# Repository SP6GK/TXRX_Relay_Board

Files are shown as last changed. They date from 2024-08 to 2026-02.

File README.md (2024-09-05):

# TXRX_Relay_Board
A PCB for switching the signal path between RX and TX in a high-power HF amplifier, such as the Forte 600. It includes RX/TX relays, an input SWR bridge, and analog input over power protection.

For the theory of operation and functionality, please refer to section 2.2.1 of the Forte 600 documentation [link](https://github.com/SP6GK/Forte-600-HF-RF-Amplifier/blob/main/Optimization_HF_amplifier_TLT_Forte600Documentation.pdf).

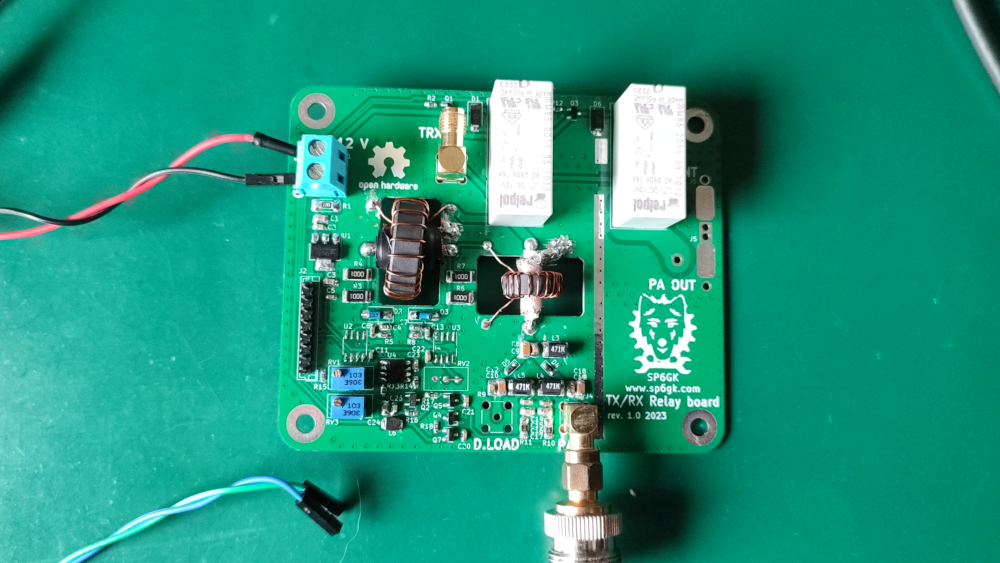
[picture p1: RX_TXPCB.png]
PCB Image


## Change log:
### 05.09.2024 - rev 1.2:
- Removed unconnected tracks and fixed some footprint libraries, as well as the relative path to the custom schematic template (thanks to vk4kyt for pointing this out).
- Changed NPN and PNP transistors to more common types.
- Added coupler measurements and simulated the overpower protection circuit in Falstad.

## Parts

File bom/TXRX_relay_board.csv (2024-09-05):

Reference | Value | Datasheet | Footprint | Qty | DNP
C1,C2,C4,C6,C7,C8,C9,C10,C13,C15,C16,C17,C19,C21,C23 | 100n | ~ | -- mixed values -- | 15
C3,C5,C14 | 22n | ~ | Capacitor_SMD:C_0805_2012Metric_Pad1.18x1.45mm_HandSolder | 3
C11,C12,C20 | 1u | ~ | Capacitor_SMD:C_0805_2012Metric_Pad1.18x1.45mm_HandSolder | 3
C18,C22 | 10u | ~ | Capacitor_SMD:C_0805_2012Metric_Pad1.18x1.45mm_HandSolder | 2
D1,D8 | 1N4007 | http://www.vishay.com/docs/88503/1n4001.pdf | Diode_SMD:D_SMA | 2
D2,D3 | Schottky | https://www.vishay.com/docs/85748/1n4148w.pdf | Diode_SMD:D_SMA | 2
D4,D5 | BAP64 | https://www.vishay.com/docs/85722/1n4448w.pdf | Diode_SMD:D_SOD-323_HandSoldering | 2
D6,D7 | D_TVS | ~ | Diode_SMD:D_SOD-323 | 2
J1 | Screw_Terminal_01x02 | ~ | TerminalBlock:TerminalBlock_bornier-2_P5.08mm | 1
J2 | Conn_01x08 | ~ | Connector_JST:JST_EH_B8B-EH-A_1x08_P2.50mm_Vertical | 1
J3 | IN | ~ | Connector_Coaxial:SMA_Amphenol_901-144_Vertical | 1
J4 | IN_RF_Deck | ~ | Connector_Coaxial:SMA_Amphenol_901-144_Vertical | 1
J5 | OUT_RF_Deck | ~ | TXRX_rel_lib:Coax_solder | 1
J6 | OUT | ~ | TXRX_rel_lib:Coax_solder | 1
K1,K2 | RT314A05 | https://www.te.com/commerce/DocumentDelivery/DDEController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 | Relay_THT:Relay_SPDT_Schrack-RT1-16A-FormC_RM5mm | 2
L1,L2 | L_Ferrite_Coupled | ~ | TXRX_rel_lib:FT82_trafo | 2
L3,L5 | L_Small | ~ | Inductor_SMD:L_0603_1608Metric_Pad1.05x0.95mm_HandSolder | 2
L4,L6,L7 | 1m | ~ | Inductor_SMD:L_1812_4532Metric_Pad1.30x3.40mm_HandSolder | 3
L8 | 100u | ~ | Capacitor_SMD:C_1206_3216Metric_Pad1.33x1.80mm_HandSolder | 1
Q1,Q2,Q4,Q5,Q6 | BC807 | https://www.onsemi.com/pub/Collateral/BC808-D.pdf | Package_TO_SOT_SMD:SOT-23 | 5
Q3 | BC846 | https://assets.nexperia.com/documents/data-sheet/BC846_SER.pdf | Package_TO_SOT_SMD:SOT-23 | 1
R1,R4,R7,R13,R20,RV1 | 10k | ~ | -- mixed values -- | 6
R2,R3,R5,R6,R8,R10 | 100 | ~ | -- mixed values -- | 6
R9 | 50 | ~ | Connector_Coaxial:SMA_Amphenol_901-144_Vertical | 1
R11,R12 | 510 | ~ | Resistor_SMD:R_1206_3216Metric_Pad1.30x1.75mm_HandSolder | 2
R14,R16,R17,R18,R19 | 1k | ~ | Resistor_SMD:R_0603_1608Metric_Pad0.98x0.95mm_HandSolder | 5
R15 | 10 | ~ | Resistor_SMD:R_2010_5025Metric_Pad1.40x2.65mm_HandSolder | 1
U1 | OP07 | https://www.analog.com/media/en/technical-documentation/data-sheets/OP07.pdf | Package_SO:SOIC-8_3.9x4.9mm_P1.27mm | 1
U2 | AMS1117-5.0 | http://www.advanced-monolithic.com/pdf/ds1117.pdf | Package_TO_SOT_SMD:SOT-223-3_TabPin2 | 1

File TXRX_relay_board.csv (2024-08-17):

null | Sourced | Placed | References | Value | Footprint | Quantity
1 |  |  | C1, C3, C7, C9, C10, C11, C16, C17, C18, C20, C22, C24 | 100n | 0603 | 12
2 |  |  | C4, C6, C15 | 22n | 0805 | 3
3 |  |  | C5, C8, C14 | 100n | 0805 | 3
4 |  |  | C12, C13, C21 | 1u | 0805 | 3
5 |  |  | C19, C23 | 10u | 0805 | 2
6 |  |  | R1, R4, R7, R13, R20 | 10k | 0603 | 5
7 |  |  | R14, R16, R17, R18, R19 | 1k | 0603 | 5
8 |  |  | R2, R3, R5, R6 | 100 | 2010 | 4
9 |  |  | R8, R10 | 100 | 0603 | 2
10 |  |  | R11, R12 | 510 | 1206 | 2
11 |  |  | R9 | 50 | SMA_Vertical | 1
12 |  |  | R15 | 10 | 2010 | 1
13 |  |  | L4, L6, L7 | 1m | 1812 | 3
14 |  |  | L1, L2 | L_Ferrite_Coupled | FT82_trafo | 2
15 |  |  | L3, L5 | L_Small | 0603 | 2
16 |  |  | L8 | 100u | 1206 | 1
17 |  |  | D1, D8 | 1N4007 | D_SMA | 2
18 |  |  | D2, D3 | Schottky | D_SMA | 2
19 |  |  | D4, D5 | BAP64 | D_SOD-323 | 2
20 |  |  | D6, D7 | D_TVS | D_SOD-323 | 2
21 |  |  | U1 | OP07 | SOIC-8_3.9x4.9mm_P1.27mm | 1
22 |  |  | U2 | AMS1117-5.0 | SOT-223-3_TabPin2 | 1
23 |  |  | Q1, Q2, Q5 | MMSS8550HE3 | SOT-23 | 3
24 |  |  | K1, K2 | RT314A05 | Relay_SPDT_Schrack-RT1-16A-FormC_RM5mm | 2
25 |  |  | Q4, Q6 | PNP | SOT-23 | 2
26 |  |  | Q3 | BC847 | SOT-23 | 1
27 |  |  | RV1 | 10k | Potentiometer_Bourns_3296W_Vertical | 1
28 |  |  | J1 | Screw_Terminal_01x02 | TerminalBlock_bornier-2_P5.08mm | 1
29 |  |  | J2 | Conn_01x08 | JST_EH_B8B-EH-A_1x08_P2.50mm_Vertical | 1
30 |  |  | J3 | IN | SMA_Amphenol_901-144_Vertical | 1
31 |  |  | J4 | IN_RF_Deck | SMA_Amphenol_901-144_Vertical | 1
32 |  |  | J5 | OUT_RF_Deck | Coax_solder | 1
33 |  |  | J6 | OUT | Coax_solder | 1

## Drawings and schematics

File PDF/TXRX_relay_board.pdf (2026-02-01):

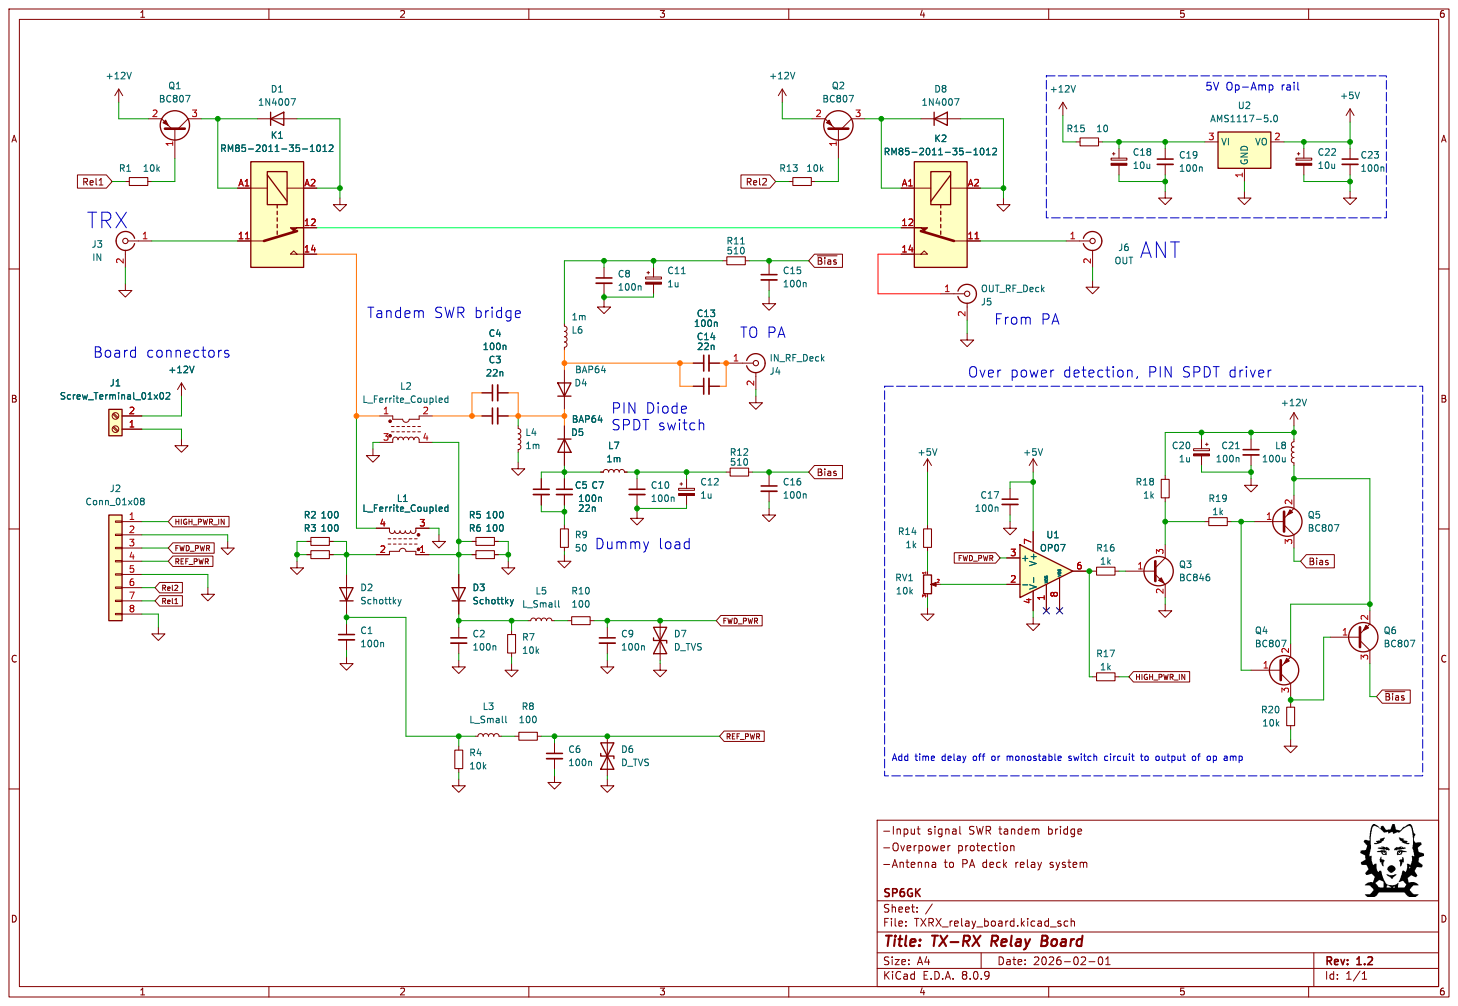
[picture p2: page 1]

Id: 1/1 Title: TX-RX Relay Board

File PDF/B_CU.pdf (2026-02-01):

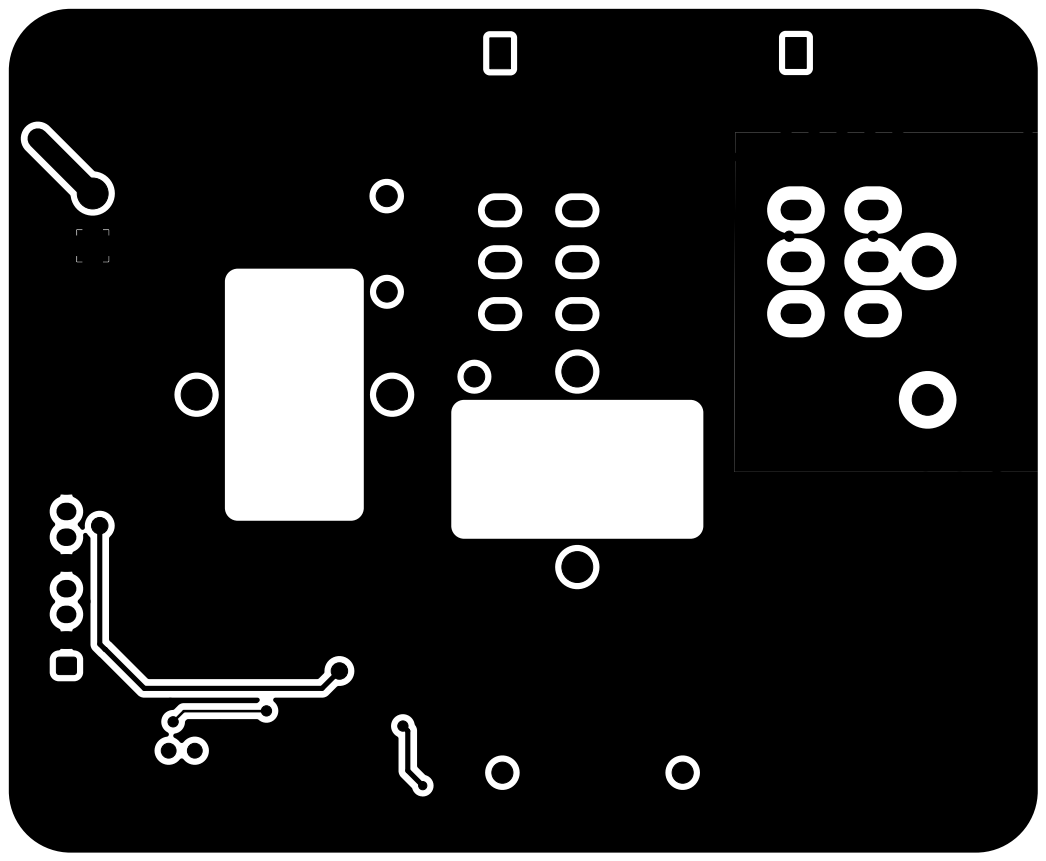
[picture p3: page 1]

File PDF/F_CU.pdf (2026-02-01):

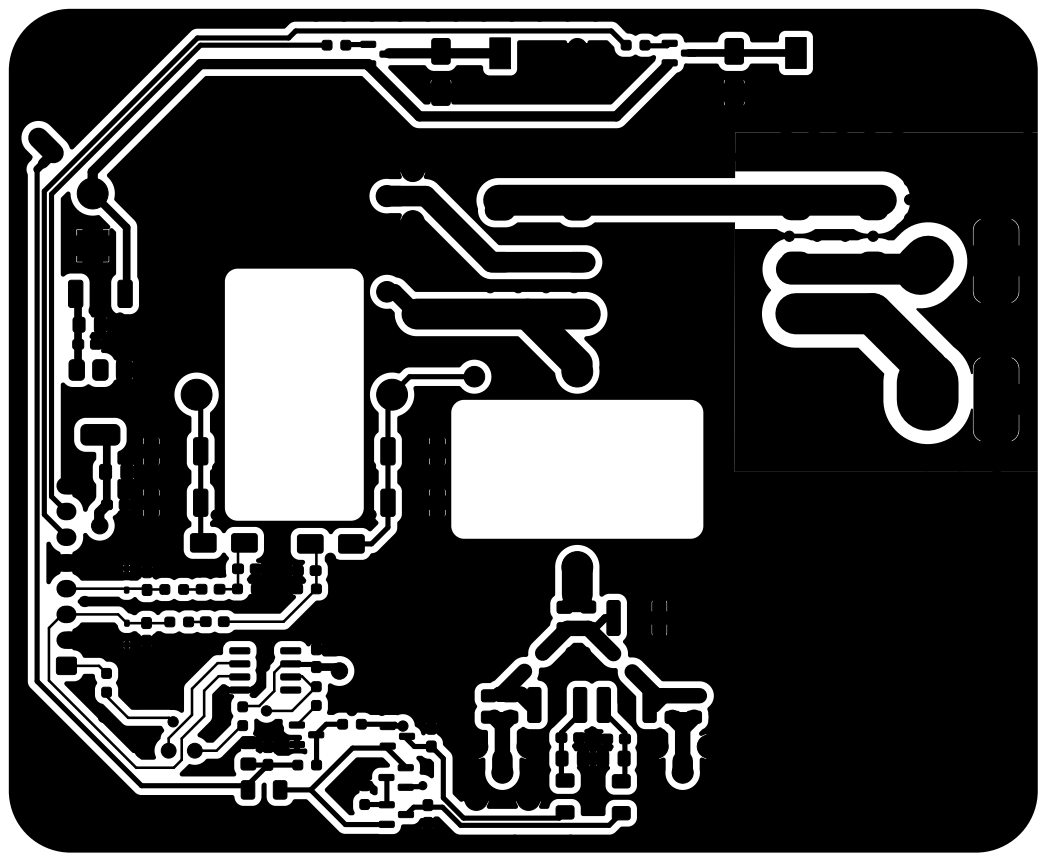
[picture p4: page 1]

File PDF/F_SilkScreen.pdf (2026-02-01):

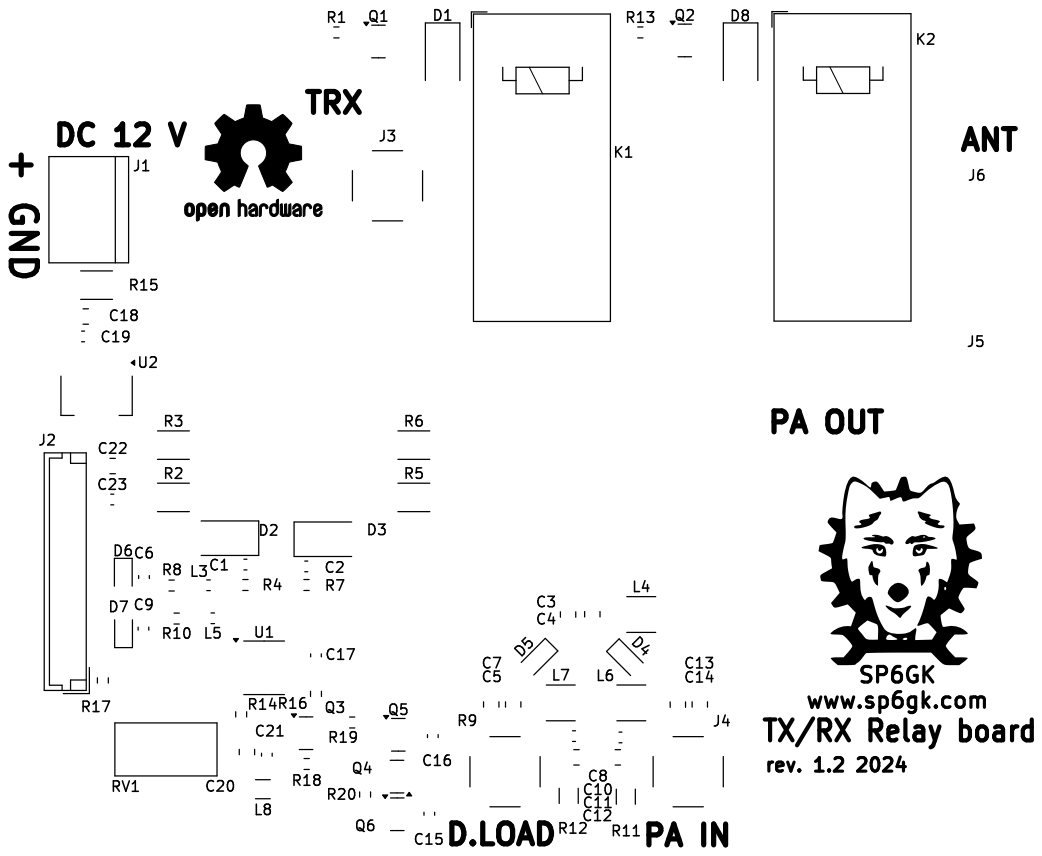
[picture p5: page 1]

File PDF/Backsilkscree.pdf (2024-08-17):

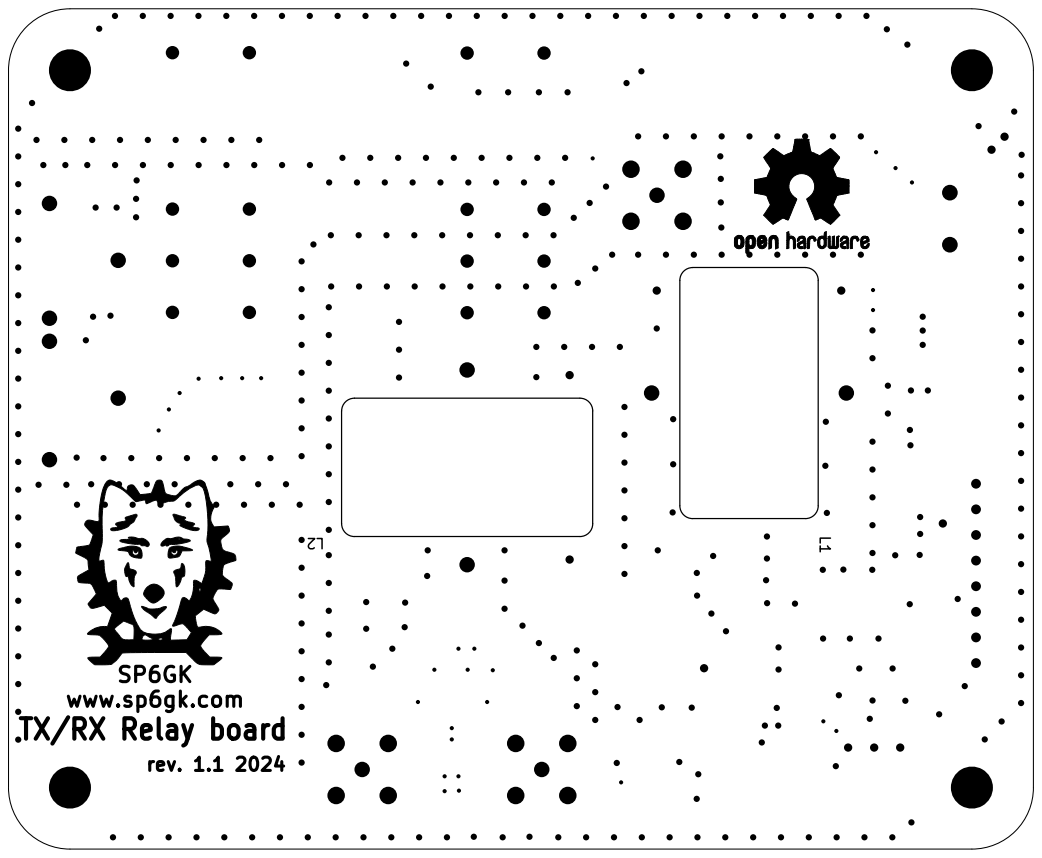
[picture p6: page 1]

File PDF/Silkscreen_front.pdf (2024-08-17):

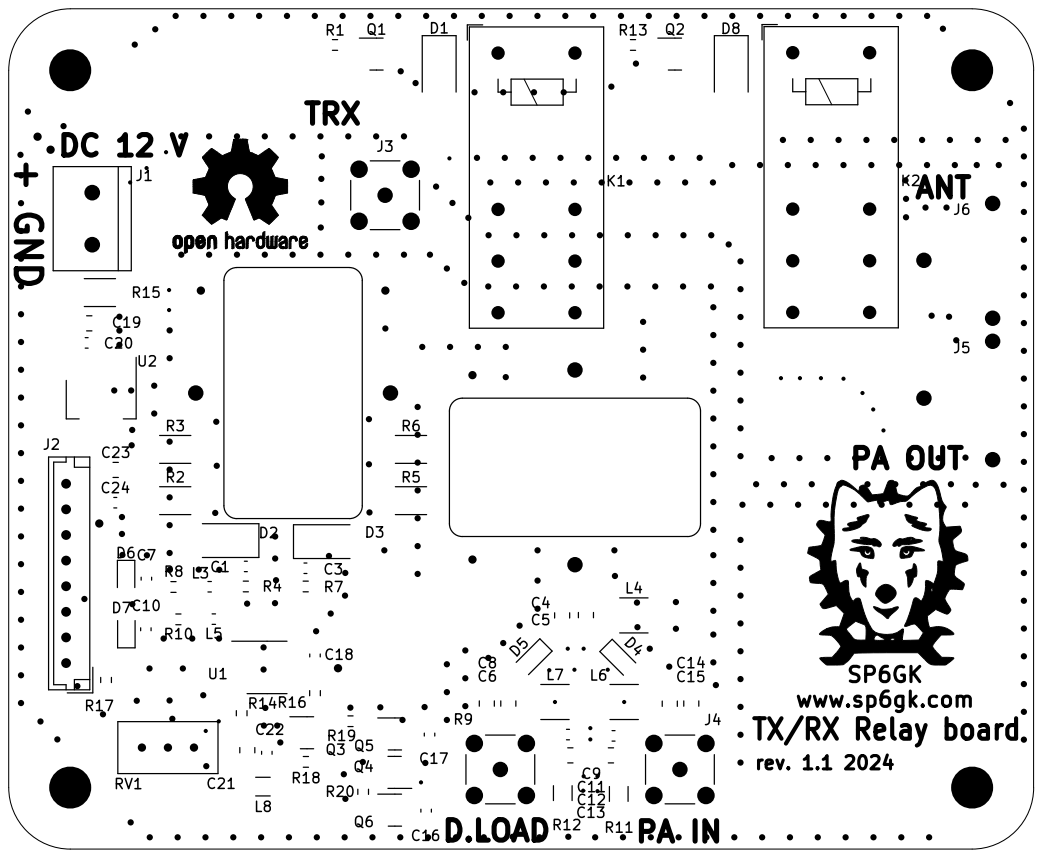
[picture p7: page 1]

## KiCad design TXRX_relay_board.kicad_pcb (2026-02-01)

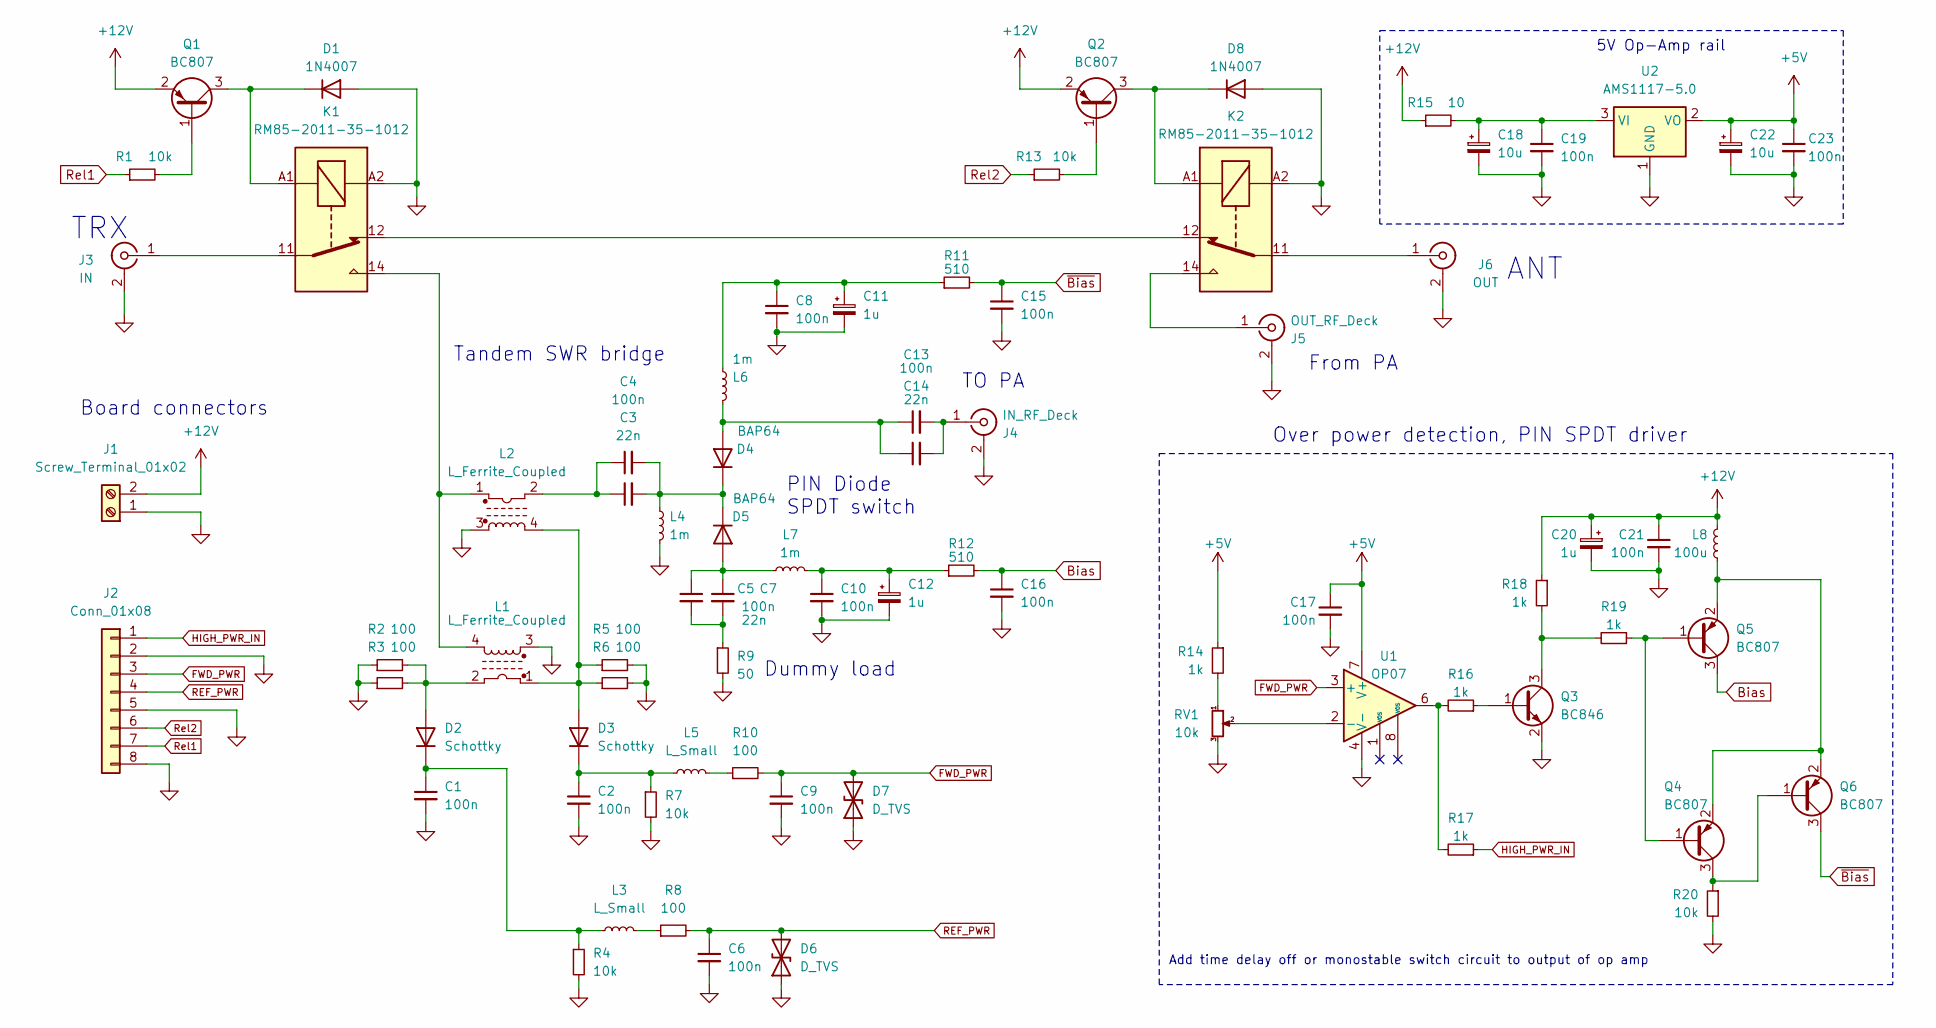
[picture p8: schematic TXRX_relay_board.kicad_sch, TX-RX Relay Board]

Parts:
C1, C2, C6, C8, C9, C10, C15, C16, C17, C19, C21, C23: 100n; C_0603_1608Metric_Pad1.08x0.95mm_HandSolder
C3, C5, C14: 22n; C_0805_2012Metric_Pad1.18x1.45mm_HandSolder
C4, C7, C13: 100n; C_0805_2012Metric_Pad1.18x1.45mm_HandSolder
C11, C12, C20: 1u; C_0805_2012Metric_Pad1.18x1.45mm_HandSolder
C18, C22: 10u; C_0805_2012Metric_Pad1.18x1.45mm_HandSolder
D1, D8: 1N4007; D_SMA
D2, D3: Schottky; D_SMA
D4, D5: BAP64; D_SOD-323_HandSoldering
D6, D7: D_TVS; D_SOD-323
J1: Screw_Terminal_01x02; TerminalBlock_bornier-2_P5.08mm
J2: Conn_01x08; JST_EH_B8B-EH-A_1x08_P2.50mm_Vertical
J3: IN; SMA_Amphenol_901-144_Vertical
J4: IN_RF_Deck; SMA_Amphenol_901-144_Vertical
J5: OUT_RF_Deck; Coax_solder
J6: OUT; Coax_solder
K1, K2: RM85-2011-35-1012; Relay_SPDT_Schrack-RT1-16A-FormC_RM5mm
L1, L2: L_Ferrite_Coupled; FT82_trafo
L3, L5: L_Small; L_0603_1608Metric_Pad1.05x0.95mm_HandSolder
L4, L6, L7: 1m; L_1812_4532Metric_Pad1.30x3.40mm_HandSolder
L8: 100u; C_1206_3216Metric_Pad1.33x1.80mm_HandSolder
Q1, Q2, Q4, Q5, Q6: BC807; SOT-23
Q3: BC846; SOT-23
R1, R4, R7, R13, R20: 10k; R_0603_1608Metric_Pad0.98x0.95mm_HandSolder
R2, R3, R5, R6: 100; R_2010_5025Metric_Pad1.40x2.65mm_HandSolder
R8, R10: 100; R_0603_1608Metric_Pad0.98x0.95mm_HandSolder
R9: 50; SMA_Amphenol_901-144_Vertical
R11, R12: 510; R_1206_3216Metric_Pad1.30x1.75mm_HandSolder
R14, R16, R17, R18, R19: 1k; R_0603_1608Metric_Pad0.98x0.95mm_HandSolder
R15: 10; R_2010_5025Metric_Pad1.40x2.65mm_HandSolder
RV1: 10k; Potentiometer_Bourns_3296W_Vertical
U1: OP07; SOIC-8_3.9x4.9mm_P1.27mm
U2: AMS1117-5.0; SOT-223-3_TabPin2

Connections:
+5V: C17.1, C22.1, C23.1, R14.1, U1.7 (V+), U2.2 (VO)
+12V: C20.1, C21.1, J1.2, L8.1, Q1.2 (E), Q2.2 (E), R15.1, R18.1
Bias: C16.1, Q5.3 (C), R12.2
FWD_PWR: C9.1, D7.2 (A2), J2.3, R10.2, U1.3 (+)
GND: C1.2, C2.2, C6.2, C8.2, C9.2, C10.2, C11.2, C12.2, C15.2, C16.2, C17.2, C18.2, C19.2, C20.2, C21.2, C22.2, C23.2, D1.2 (A), D6.1 (A1), D7.1 (A1), D8.2 (A), J1.1, J2.2, J2.5, J2.8, J3.2 (Ext), J4.2 (Ext), J5.2 (Ext), J6.2 (Ext), K1.A2, K2.A2, L1.3, L2.3, L4.2, Q3.2 (E), R2.1, R3.1, R4.2, R5.2, R6.2, R7.2, R9.2, R20.2, RV1.3, U1.4 (V-), U2.1 (GND)
HIGH_PWR_IN: J2.1, R17.1
unnamed: C3.1, C4.1, L2.2
unnamed: C5.2, C7.2, R9.1
unnamed: C10.1, C12.1, L7.2, R12.1
unnamed: C8.1, C11.1, L6.1, R11.1
unnamed: D1.1 (K), K1.A1, Q1.3 (C)
unnamed: D2.2 (A), L1.2, R2.2, R3.2
unnamed: C1.1, D2.1 (K), L3.1, R4.1
unnamed: D3.2 (A), L1.1, L2.4, R5.1, R6.1
unnamed: C2.1, D3.1 (K), L5.1, R7.1
unnamed: C13.1, C14.1, D4.2 (A), L6.2
unnamed: C3.2, C4.2, D4.1 (K), D5.1 (K), L4.1
unnamed: C5.1, C7.1, D5.2 (A), L7.1
unnamed: D8.1 (K), K2.A1, Q2.3 (C)
unnamed: J3.1 (In), K1.11
unnamed: C13.2, C14.2, J4.1 (In)
unnamed: J5.1 (In), K2.14
unnamed: J6.1 (In), K2.11
unnamed: K1.12, K2.12
unnamed: K1.14, L1.4, L2.1
unnamed: L3.2, R8.1
unnamed: L5.2, R10.1
unnamed: Q1.1 (B), R1.2
unnamed: Q2.1 (B), R13.2
unnamed: Q3.1 (B), R16.1
unnamed: Q3.3 (C), R18.2, R19.2
unnamed: Q4.1 (B), Q5.1 (B), R19.1
unnamed: Q4.3 (C), Q6.1 (B), R20.1
unnamed: L8.2, Q4.2 (E), Q5.2 (E), Q6.2 (E)
unnamed: R14.2, RV1.1
unnamed: R16.2, R17.2, U1.6
unnamed: RV1.2, U1.2 (-)
unnamed: C18.1, C19.1, R15.2, U2.3 (VI)
REF_PWR: C6.1, D6.2 (A2), J2.4, R8.2
Rel1: J2.7, R1.1
Rel2: J2.6, R13.1
~Bias: C15.1, Q6.3 (C), R11.2

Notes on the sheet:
Board connectors
5V Op-Amp rail
From PA
TRX
ANT
Dummy load
TO PA
PIN Diode SPDT switch
Tandem SWR bridge
Add time delay off or monostable switch circuit to output of op amp
Over power detection, PIN SPDT driver

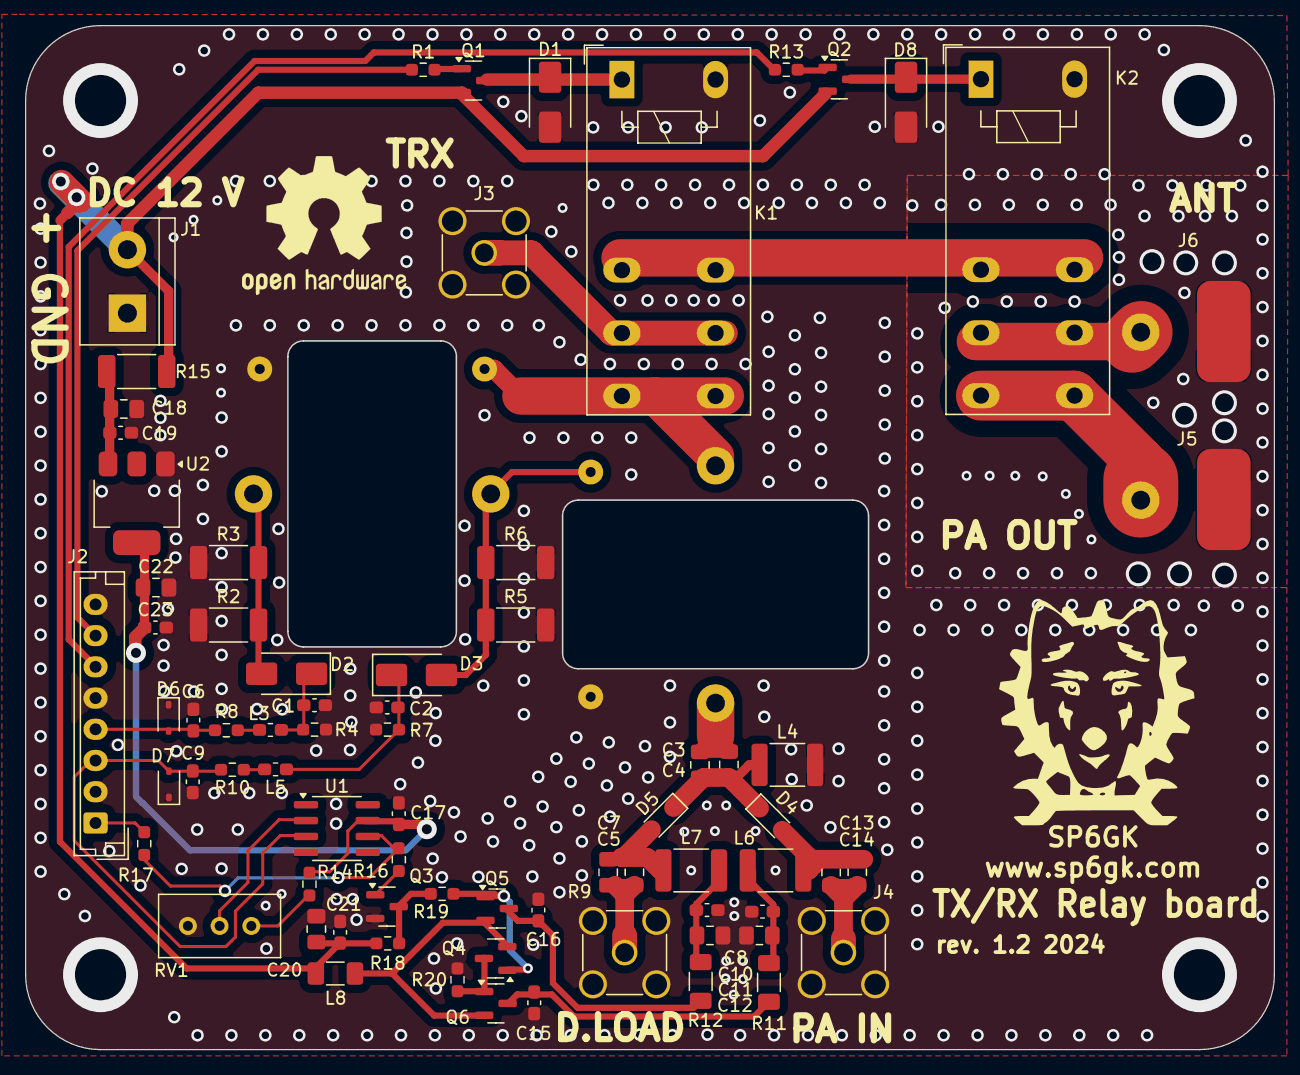
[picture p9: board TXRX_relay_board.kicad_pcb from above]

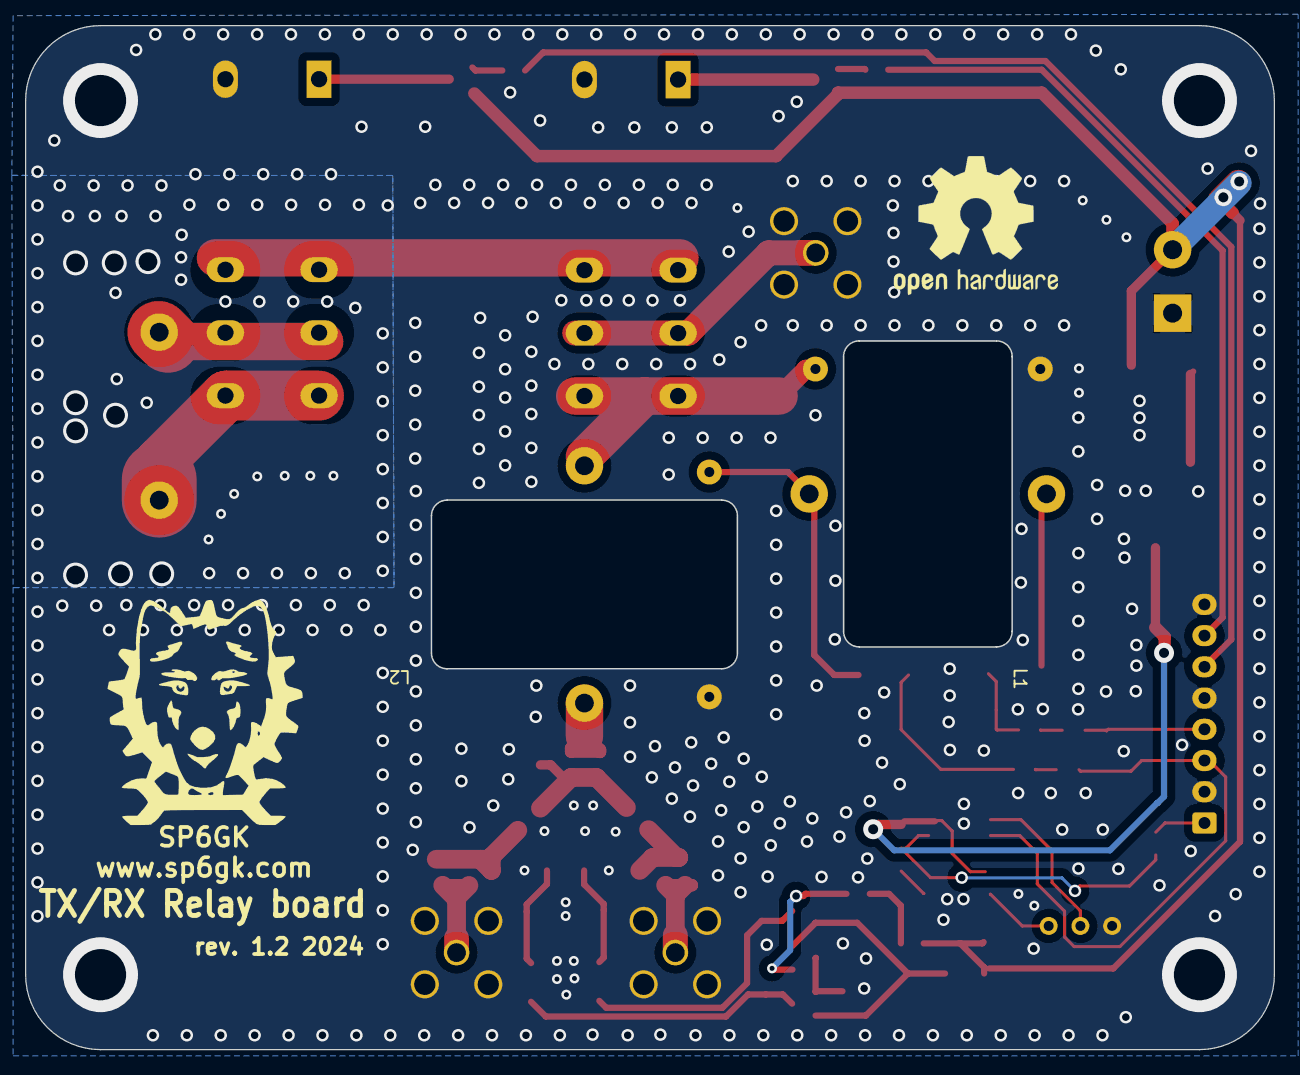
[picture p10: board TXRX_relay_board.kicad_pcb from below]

Board: 2 copper layers, 100.0 x 82.0 mm, 76 parts (2 on the bottom side), 42 nets.

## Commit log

2024-08-17 PCB photo
2024-09-05 rev 1.2
    Minor fixes, coupler measurements, falstad simulation of over power protection
    [Coupler_mes1.ods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]
2026-02-01 Revision 1.2, fixed name of RLs, removed op amps in detector
    [TXRX_relay_board-B_Cu.gbr, TXRX_relay_board-B_Mask.gbr, TXRX_relay_board-B_Paste.gbr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]
